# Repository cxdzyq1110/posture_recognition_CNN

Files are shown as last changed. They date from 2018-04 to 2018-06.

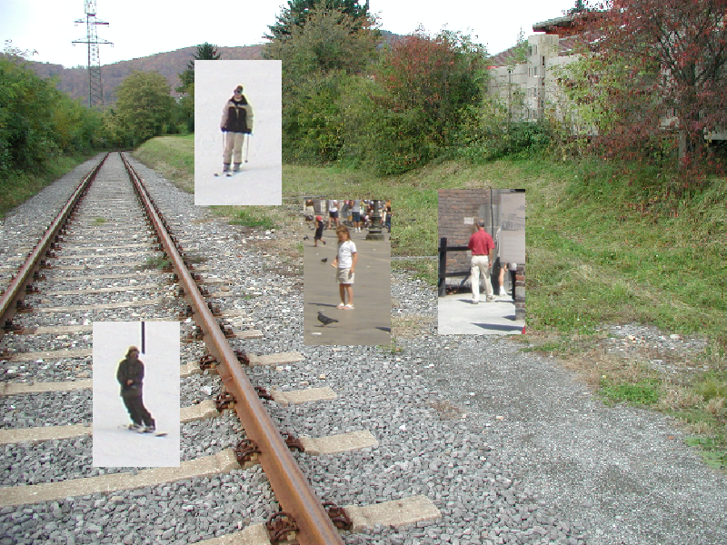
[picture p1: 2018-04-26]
projects/matlab/picture/test_hog_svm/no_person__no_bike_218.png

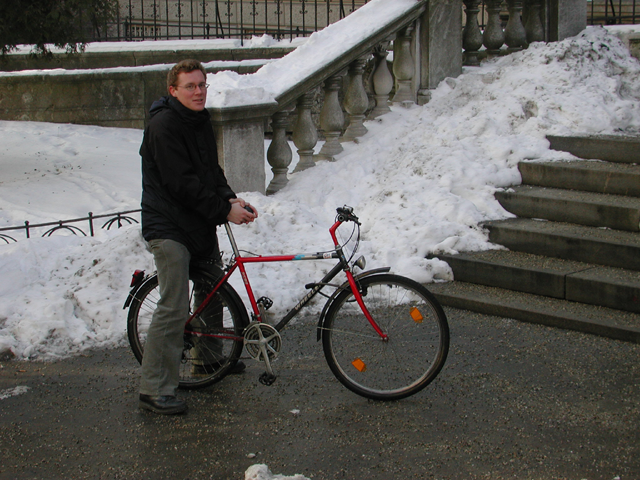
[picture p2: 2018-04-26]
projects/matlab/hog_svm/test.png

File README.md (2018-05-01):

# posture recognition based on CNN
To help machines learn what we human beings are doing via a camera is important. Once it comes true, machines can make different responses to all kinds of human's postures. But the process is very difficult as well, because usually it is very slow and power-consuming, and requires a very large memory space. Here we focus on real-time posture recognition, and try to make the machine "know" what posture we make. The posture recognition system is consisted of DE10-Nano SoC FPGA Kit, a camera, and an HDMI monitor. SoC FPGA captures video streams from the camera, recognizes human postures with a CNN model, and finally shows the original video and classification result (standing, walking, waving, etc.) via HDMI interface.

## documents
We upload our thesis here. And the details of the project is demonstrated.

## projects
We upload our projects, including Matlab, Python, and Quartus.  
And the software version is:  
> Matlab r2017b  
> Python 3.6.3  
> Anaconda 5.1.0  
> TensorFlow-gpu 1.3.0  
> Quartus 14.0

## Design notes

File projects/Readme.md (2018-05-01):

# ad9pcb					
> in the directory, there are files for PCB design of our pin-board between camera and DE10-Nano  
and We use Altium Design 9
				
# python					
> python codes using TensorFlow framework, train CNN and generate NPU instructions, and CNN parameters  
Anaconda 5.1.0  
Python 3.6  
Tensorflow r1.3  
							
# matlab					
> Matlab codes for LK optical flow, HOG+SVM simulation and ISA-NPU testing  
Matlab 2017b
				
# zFPGA\_lk\_optical\_flow		
> LK optical flow design for FPGA

# zFPGA\_cnn\_inst\_set\_arch	
> ISA-NPU design for FPGA

# zFPGA\_hog\_svm\_fpga		
> HOG+SVM static pedestrian detection for FPGA

# zFPGA\_DE10\_NANO\_SoC		
> total posture recognition system  
Quartus 14.0

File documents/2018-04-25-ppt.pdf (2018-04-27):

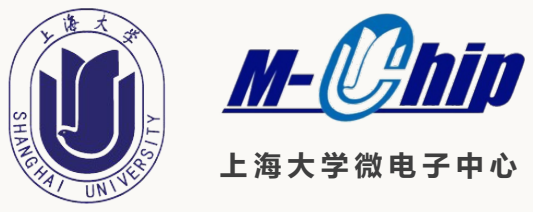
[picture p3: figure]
上海大学微电子中心

# Posture Recognition Based on Deep Learning

### Team: PR023

### Member: Xudong Chen, Yuqi Zhou, Mengjie Li Adviser: Prof. Zhangjin Chen

Microelectronics R & D Center, Shanghai University

## 1 Posture Recognition Based on Vision

Pedestrian Detection: find where the person is
Posture Recognition: recognize what posture it is Applications: somatic games, abnormal behavior detection, …

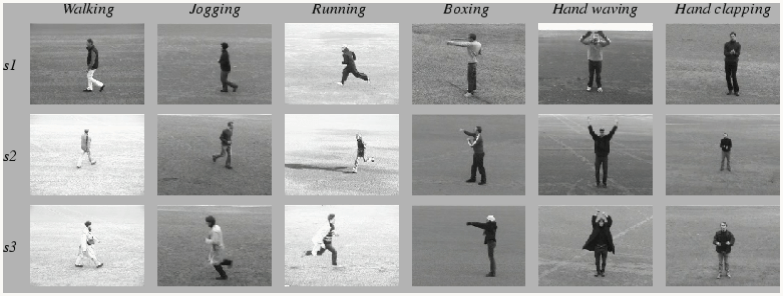
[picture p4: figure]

## 2 Posture Recognition Scheme

Two-Stream Convolution：compute optical flow in the video stream, and use video and optical flow as the input channels of CNN to recognize the posture
ISA-NPU: ADD / MULT / CONV / POOL / SIGM / TANH / …

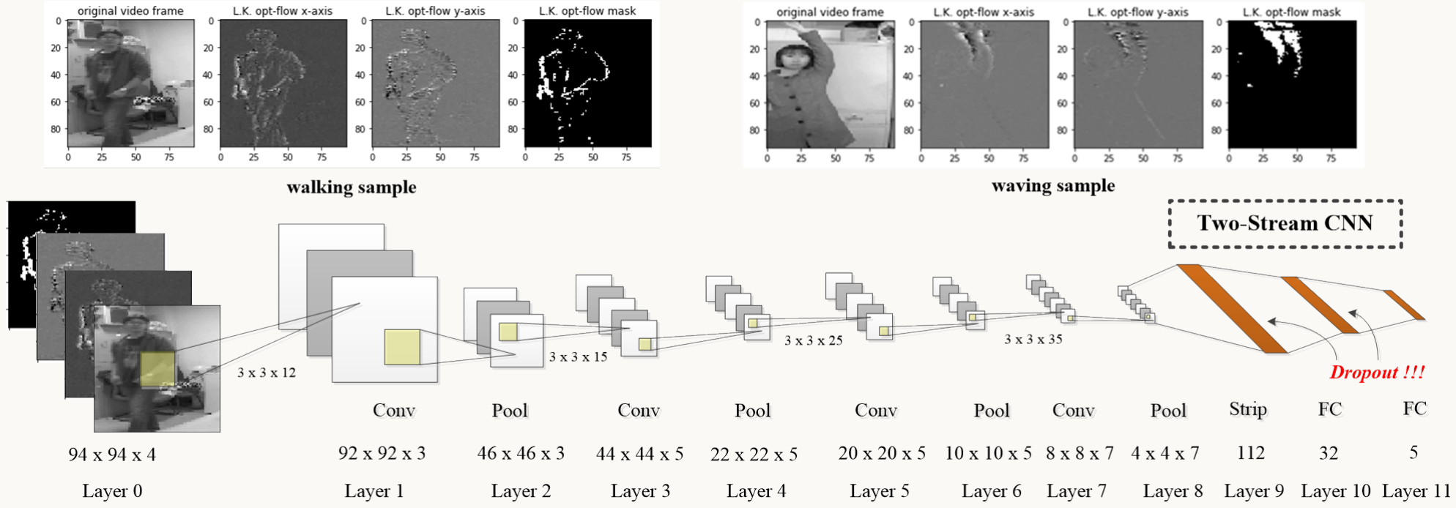
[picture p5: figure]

## 4 The Flow of Posture Recognition

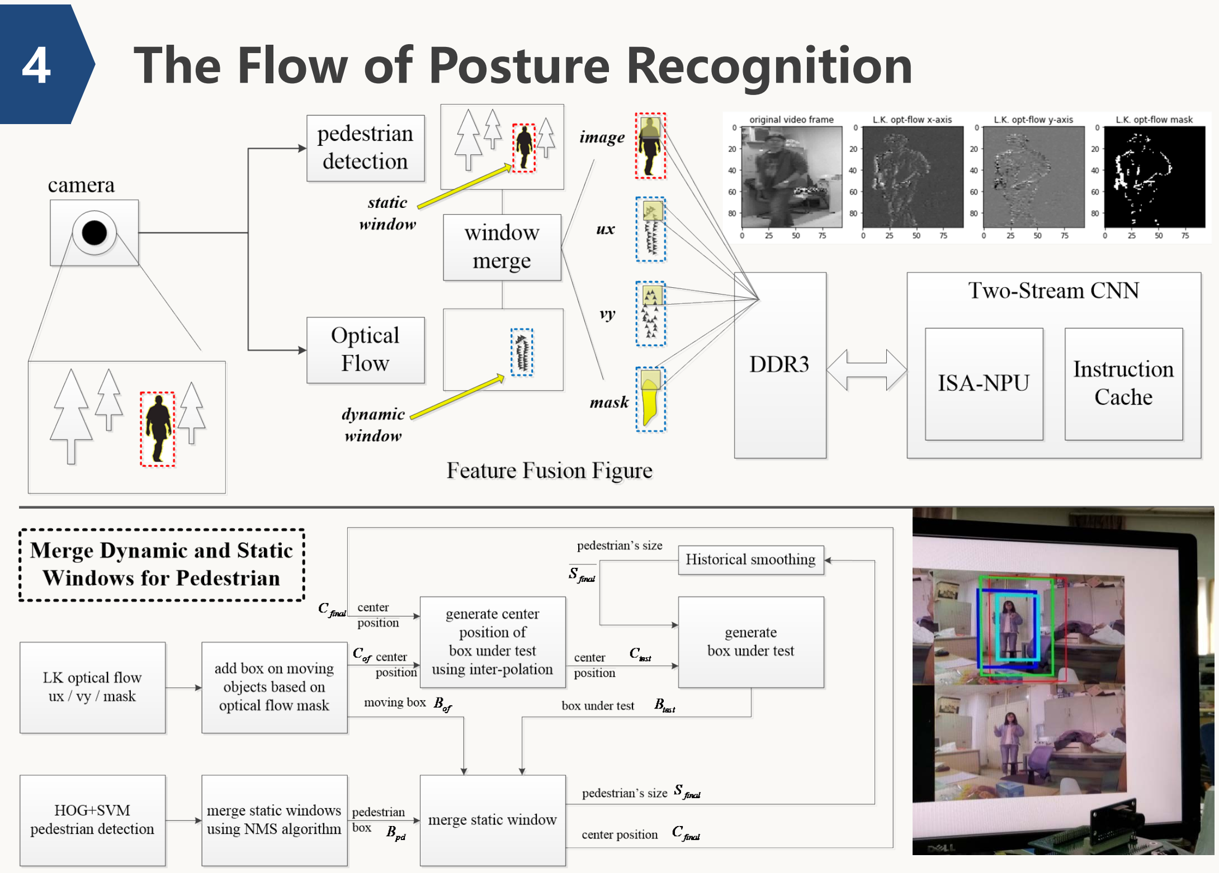
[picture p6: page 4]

## 5 Framework of the System

Co-process of software and hardware on DE10-Nano FPGA：optical flow, static detection, ISA-NPU, memory scheduler, video output; HPS：add box, NPU command；
Matlab：filter samples; Python：train the CNN model

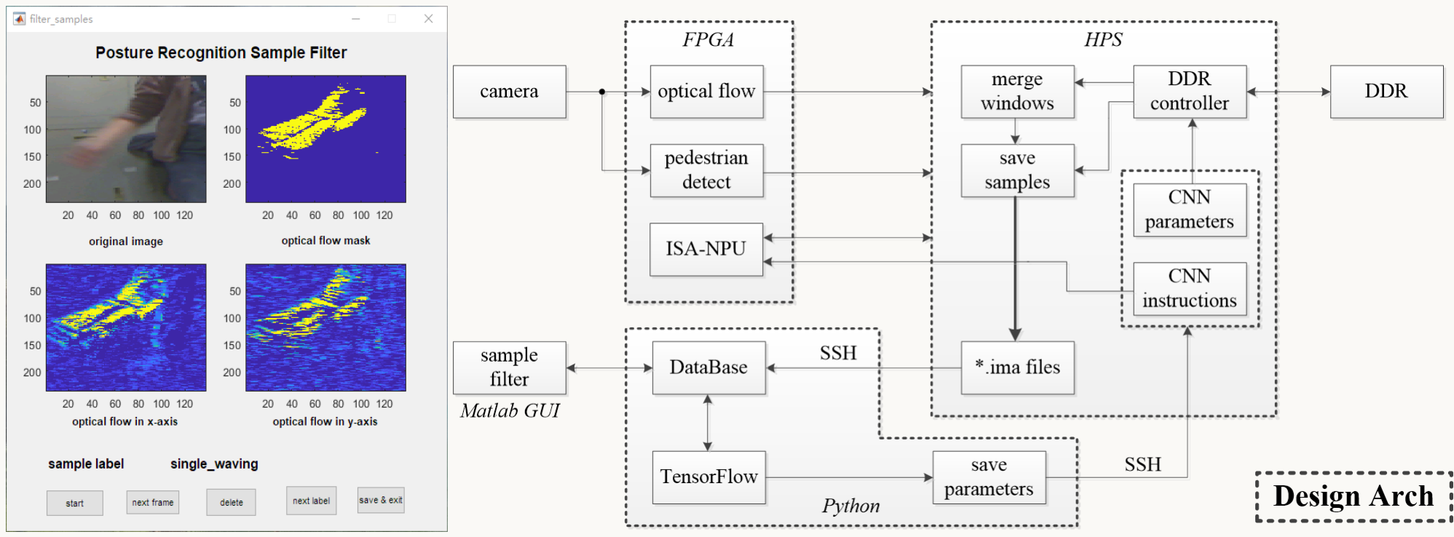
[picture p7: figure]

## 6 Performance of the System

Performance | LK Optical Flow | HOG + SVM | ISA-NPU
Speed | Fmax | 118.68 MHz | 76.8 MHz | 79.6 MHz
| Period | 800 x 600 | 800 x 600 | 814,177
| FPS | 247 | 160 | 97.7
Area | ALMs | 7,799 | 14,105 | 3,530
| Memory Bits | 188,202 | 1,167,512 | 73,984
| DSPs | 41 | 16 | 43
Performance | LK Optical Flow | HOG + SVM | ISA-NPU
Speed | Fmax | 35 MHz | 35 MHz | 66.67 MHz
| Period | 800 x 600 | 800 x 600 | 814,177
| FPS | 20 | 20 | 3.84
Performance | | Dynamic Window | Static Window | Merge Window
Time | | 70.2 ms | 11 us | 8 us

The theoretic limit of performance of modules

The experimental performance of hardware and software modules

Item | ALMs | Memory Bits | DSPs
Utility | 37,933 ( 91 % ) | 2,513,876 ( 44 % ) | 106 ( 95 % )

The resource usage of the total hardware system

## Conclusion and Outlook

We propose a posture recognition system that：
1. process optical flow, static pedestrian detection very fast, actually it is pipeline processing;
2. flexible for different CNN models, if the model changes, only parameters and NPU instructions should be re-generated;
3. recognize four postures with high precision: standing, squatting, waving and walking;
We can improve the system later in these aspects:

### 1. more postures can be recognized once the CNN model

grows；

### 2. high performance can be achieved if bandwidth of DDR

increases

7

# Thanks for Your Attention

GitHub https://github.com/cxdzyq1110/posture_recognition_CNN

Name Xudong Chen, Yuqi Zhou, Mengjie Li

Email chenxudong0318@gmail.com

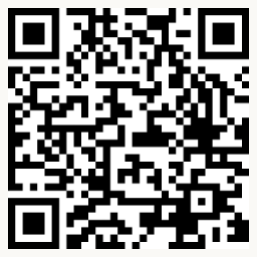
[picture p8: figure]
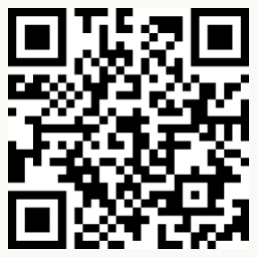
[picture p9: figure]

Team PR023 | innovatefpga | GitHub

## 6 Hardware Architecture

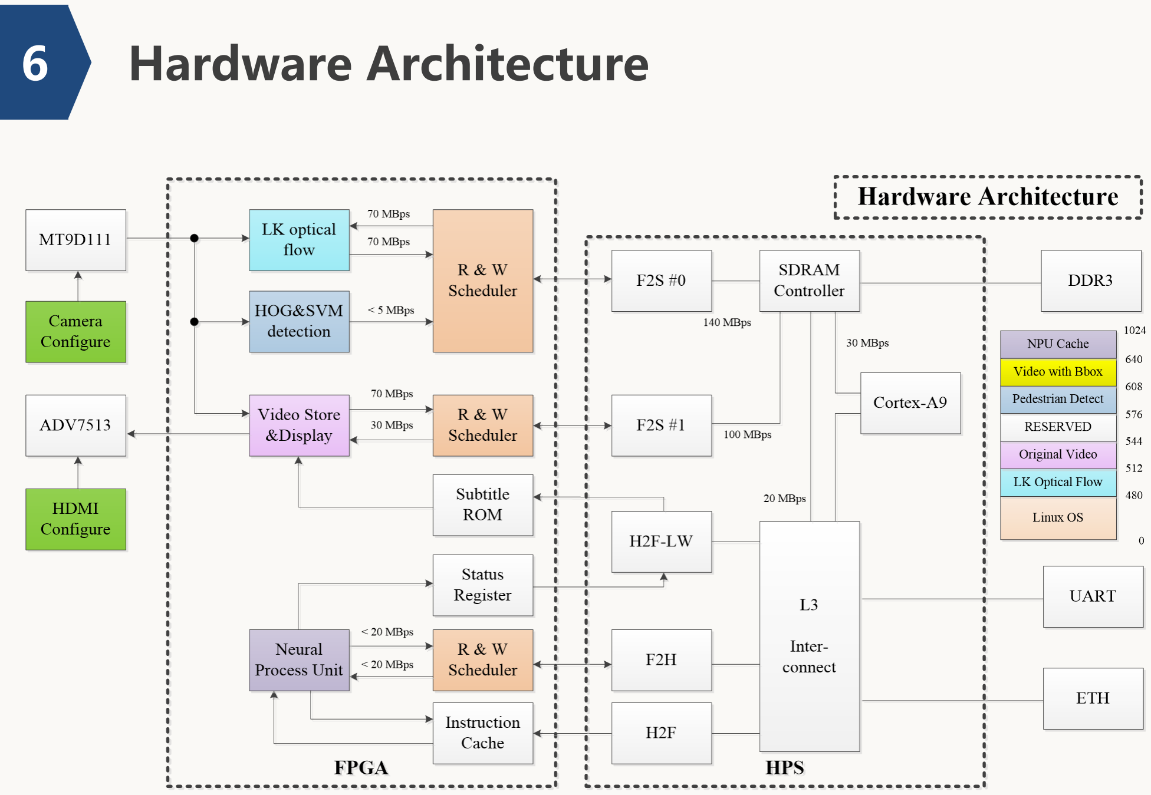
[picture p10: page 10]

## 7 Software Architecture

### Different Mode： 1. running mode：merge windows and recognize 2. sampling mode：merge windows and sample 3. testcnn mode：use training set to test CNN

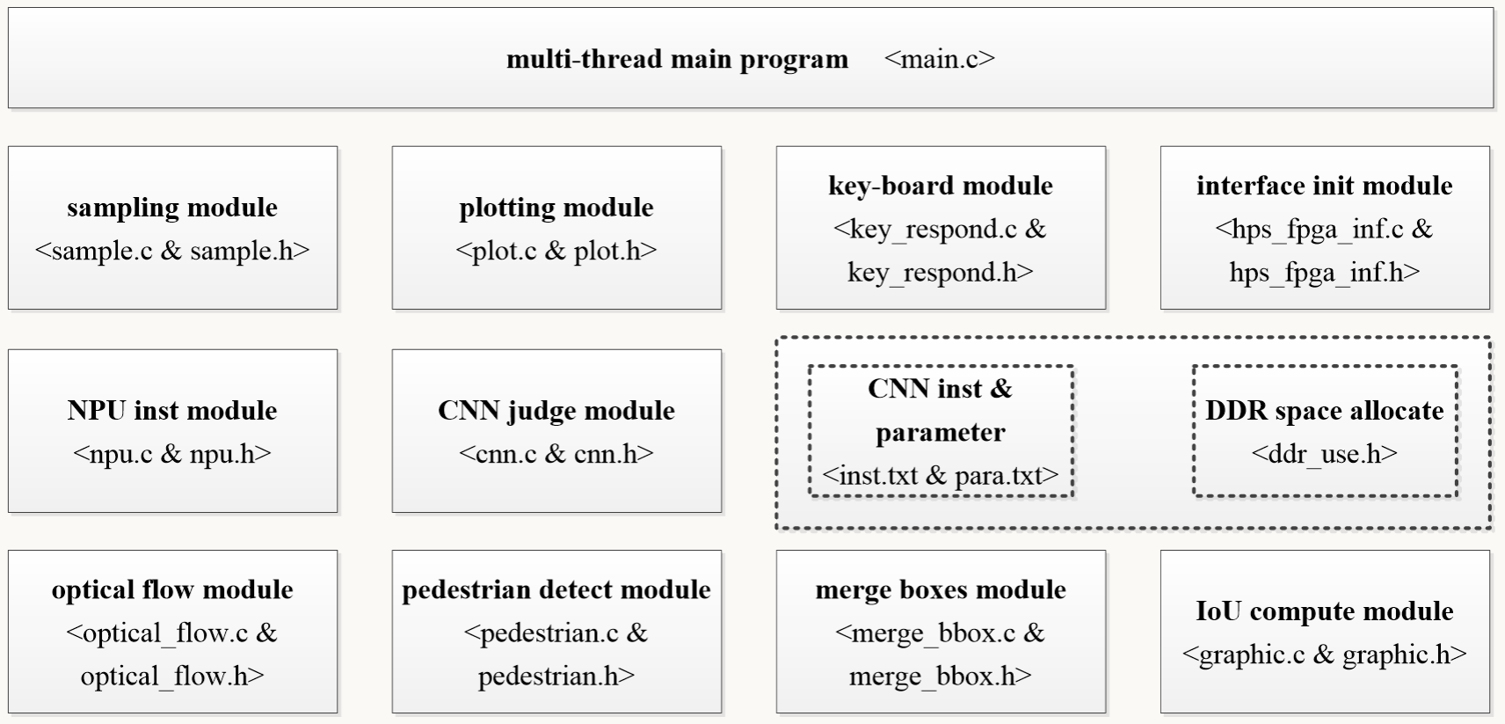
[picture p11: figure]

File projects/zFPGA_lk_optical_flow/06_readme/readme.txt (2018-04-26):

2018-02-06: 光流法的modelsim仿真+matlab绘图验证，另外，修正mux-port模块，提升DDR带宽利用率
			通过设置屏蔽字，巧妙地避开了DCFIFO的rdempty的1-clock延时，为光流法的运作提供了带宽支持
				单端口利用率：0-50%
				多端口利用率：0-100%
				
2018-02-21: 修改了光流法计算结果的存储格式
			|31|30|		29: 15		|		14:0		|
			|0 |M |     ux			|		vy			|
			其中，M表示Mask，即光流法计算结果，经过动态阈值比较后的判定结果
			ux/vy分别是计算的结果（光流速度），其运算结果缩小8倍得到的结果（即optical_u/optical_v[17:3]）

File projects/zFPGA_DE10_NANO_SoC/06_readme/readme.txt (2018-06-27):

// 基于深度学习的姿势识别项目
调试的记录
----------------------------
2018-01-25：
1. h2f/h2f_lw添加avalon_mm_pipeline是不行的，linux的内核boot不了
2. f2h/f2s都是可以增加avalon接口的
3. 在grhd工程的基础上进行修改，现在可以往DDR里面存放MT9D111数据（空间512~544MB）
4. 但是摄像头的配置还有问题（似乎RGB565数据流有问题）
5. 或者也有可能是DDR写入不正确

需要验证：
1. 是摄像头数据流问题？
2. 还是DDR写入的时候数据有丢失？
	（可以写一个调试的接口，按下按钮往DDR里面连续写入XX数据，然后读出，比较正确与否）
	
---------
2018-01-25:
1. 查明原因：是MT9D111的配置有问题，有几个地方是需要delay才行的！
	然后改好以后，在linux里面采集DDR数据，发送到PC显示，正确？
2. 关于ADV7513的配置还有问题！

---------
2018-01-27:
1. 发现DDR读取的时候，数量不对；
	a. 修改mux_port模块，改成了cam_rot_amp项目的即可
	b. 另外，解耦用的2-port的RAM也有时序问题？换成DCFIFO进行解耦（同时参考DCFIFO的q和rdempty）
	c. 再有就是MON_H_rd / MON_rd_req的生成也有问题（总之还是要用状态机控制才安全！）
2. 另外，DDR出来的数据会写入到FIFO里面，但是这个FIFO的VGA读取还有问题？
	应该是综合或者烧录的问题，多编译/烧录几次又可以了
3. 出现视频显示不稳定的情况（水平位移 & 上方噪声条）
	修改了HDMI的时序，又好了

2018-01-31：
1. 将HDMI改成是1024x768输出，65MHz像素时钟
2. ADV7513_DE的赋值需要修改成  ADV7513_DE <= (ADV7513_VCnt<VA && ADV7513_HCnt<HA);
3. 像素时钟的极性是不是也有影响？的确如此！看来走线延时挺大！

----------------------------------
2018-02-02:
1. 发现HPS正在preloader/u-boot的时候，FPGA不能去读写DDR，不然linux启动不了（或者说，u-boot会出错）
2. 发现FPGA把摄像头数据写入进去DDR没有问题（ima+matlab验证），但是ADV7513的HDMI输出数据源有问题
	查明原因：多读了很多的像素点数据！
	但是为什么会多读，似乎是cstate这个状态机的问题——被综合掉了？没有跳转逻辑，这就很奇怪！
	不对，在quartus里面，cstate会被综合成：cstate.0000 / cstate.0001 / cstate.0010 / cstate.0011 / ...
3. 另外，在modelsim仿真中发现，mux-port的port_num_fifo有溢出的可能，调整到4bx4096w大小
4. 还有，DDR中读取video视频数据，只是超前一行，不再超前两行
	读取的启动发生在：超前一行 & HDMI输出正好过了周围白色区域
	统计：DDR中读取出来的像素点数量 == 800
	统计：HDMI申请的像素点数量 == 800
	
-------------
2018-02-02:
1. 发现HDMI<--FIFO<--DDR读取的像素点数量不足够800点？超前2行进行读取？
2. 其实是因为DDR读取的时候太慢造成的，将HDMI输出降低到24fps的帧速，就没有问题了
3. 但是现在的问题在于：图像有水平（漂移造成？）的噪点，不确定是什么原因导致的
	如果只是输出彩条，那么图像很稳定，说明ADV7513 <-- FPGA这里没有问题
	猜测：	1. MT9D111的采集有偏差
			2. DDR读写有偏差
	
	测试：增加一个拨码开关，如果SW[0]==1，那么从DDR里读取出来的数据就是变成彩条，否则保持DDR理数据
			看看到底是DDR读取的问题，还是DDR写入/摄像头输出的问题？
			// 然后，可以根据SW拨码开关的状态，配置写入到line_buffer的数据是video数据/彩条测试图样
			发现：很稳定的彩色条纹！那么问题就出在DDR写入/读取/摄像头采集的问题！
	而通过HPS直接读取DDR中的图像，发现没有所谓的条纹问题，说明问题就出在DDR读取的数据不对！
	
	// 试图将MT9D111的MCLK加到65MHz，能不能提到系统的工作频率？
	无奈之下，选择替换mux-port多端口读写模块，牺牲一半的带宽，总之就是这个模块的问题！
	
	另外，修正了DDR中，512MB~1024MB都是视频采集的缓冲区（8MB/frame x 64frames）
	验证的时候，分别在512MB和1016MB的地方，读取一下DDR里面的数据，做成ima文件，发送到PC，看看有没有视频
	发现linux死机！看来一定要有相应的防范措施，防止linux的OS访问物理内存的高512MB数据，但是可以通过mmap来进行APP访问
	
---------
2018-02-02: 预留出512~1024MB地址的DDR存放视频数据
	尝试解决修正了DDR中，512MB~1024MB都是视频采集的缓冲区（8MB/frame x 64frames），导致linux死机的问题
	在software\spl_bsp\uboot-socfpga\include\configs\socfpga_common.h文件中，修改PHYS_SDRAM_1_SIZE参数，使得preloader和uboot只允许512MB的SDRAM
	不正确！
	实际上，是要在uboot的时候，修改mmcboot这个变量，添加mem=512M就可以实现高512MB空间预留给摄像头数据了
	验证：测试了512 MB 和1016MB 地址的8MB图像数据，发现确实是采集到的图像

---------
2018-02-04：将HDMI输出切割成4块，分别是【原始图像】【骨架图】【光流图】【判别图】
	另外，准备一个礼拜完成【骨架】【光流】的计算

---------
2018-02-06: 光流法的modelsim仿真+matlab绘图验证，另外，修正mux-port模块，提升DDR带宽利用率
			通过设置屏蔽字，巧妙地避开了DCFIFO的rdempty的1-clock延时，为光流法的运作提供了带宽支持
				单端口利用率：0-50%
				多端口利用率：0-100%
				
---------
2018-02-08: 修正了LK光流法模型中的一些小bug
			1. 在ux/vy计算完成后，需要计算速度的大小，这里使用了int_cordic_core模块，但是这个模块是32/16的配置，所以需要作出相应的修正
			2. 不对！其实是cordic算法中，ROM的初始化没有做好！
			3. 应该是VSYNC上升（有效）超前HSYNC（上升/有效）  6个PCLK，但是VSYNC下降又滞后于HSYNC下降6个PCLK
				也就是说：LK光流法模块里面没有来得及读取出DDR里面的（上一帧视频图像）
			4. 调换LK光流法和ADV7513-HDMI输出（对DDR的）读取接口port，将LK光流法的优先级排在HDMI输出的前面，结果发现HDMI输出受阻，看来F2S读取的带宽确实是需要认真考虑的问题
			5. 尝试：将MT9D111的采集时钟降一半，变成36 MHz的，这样整个系统的帧频也下降
			6. 另外，LK光流法读取到的“上一帧”好像有些问题？也不对，应该是1. LK光流结果的存储->2. HDMI输出时候读取LK光流，这两步存在问题
			7. 原来是 video_process 模块没有将 正在写入的块 CURR_FRAME 和上一次写入的块 PREV_FRAME 传递到 OpticalFlowLK 模块中去！
-----------------			
2018-02-12: 在LK光流法模块中增加了动态阈值的功能
	1. 动态阈值 + 4阶均值滤波
	
-------------------------------
2018-02-13：将项目迁移到DE10-Nano开发板下
	集成了MT9D111摄像头采集+LK光流计算+HDMI输出
	480 MB --> Linux OS
	32 MB --> LK Optical Flow
	512 MB --> Video RAM

-------------------------------
2018-02-21: 修改了光流法计算结果的存储格式
			|31|30|		29: 15		|		14:0		|
			|1 |M |     ux			|		vy			|
			[31]的1用来告诉ADV7513的line-buffer，这个数据是光流法的阈值判断结果，只要用[30]扩充就可以了
			其中，M表示Mask，即光流法计算结果，经过动态阈值比较后的判定结果
			ux/vy分别是计算的结果（光流速度），其运算结果缩小8倍得到的结果（即optical_u/optical_v[17:3]）

-------------------------------			
2018-03-02: 增加了HOG+SVM的行人检测代码，能将检测的结果保存到DDR的448MB~480 MB区间内
			存储的格式为：   [aa][bbbbbbbb][hhhhhhhhhhh][vvvvvvvvvvv]
			其中，aa=00:无效数据/ aa=01:表示1/1比例尺 / aa=10：表示1/2比例尺  /  aa=11:表示1/4比例尺
			bbbbbbbb = score/4096，直接移位12bit，应该足够存下了
			最后，hhhhhhhhh/vvvvvvvv就是bbox左上角所处的坐标位置
			另外，发现两个大问题：
			1. 板子的资源可能不太够
			2. OpenCL和普通的rtl怎么一同进行编译
			3. 怎么在14.0下开发OpenCL程序
	
	448 MB --> Linux OS
	32 MB --> Pedestrian Detection Result
	32 MB --> LK Optical Flow
	512 MB --> Video RAM		
--------------------
2018-03-03: 发现SVM判决器中的数据有溢出的情况
	1. 8-bit有符号数保存SVM中的w/b参数，所有参数x64取整（floor）
	2. 调整hog_svm_pd_rtl模块中的输出移位
	3. 调整hog_svm_pd_800x600/400x300/200x150中的行人检测阈值
	
	另外，HSG-SVM的参数，一定要用round进行【四舍五入】取整
	如果简单的ceil/floor进行向上/向下取整，会存在累积误差
	
	此外，1：2和1：4两个缩放后的图像中，HSG特征和matlab的结果有很大的区别，将近±33%，几乎就是完全不对的
	1：1原始图像的HSG特征和matlab结果差不多是±8%的误差

---------------
2018-03-06：使用Avalon-MM master/slave translator，将HPS和FPGA之间的AXI接口转换成Avalon接口
	1. F2S直接Avalon-MM，外部MT9D111摄像头采集&LK光流计算&行人检测结果
	2. F2H通过Avalon-MM-Master-Translator，实现HDMI数据的读取
	3. H2F通过Avalon-MM-Slave-Translator，实现HPS向FPGA传输数据，但是速率很慢，应该是AXI/Avalon协议转换造成的
	PS！后续应该要有AXI接口数据的直接读取，测试一下传输速率
	
----------
2018-03-07: 查明h2f/h2f_lw速度较慢的原因：Linux的问题
	1. 另外，通过Avalon-MM-Slave-Translator转接出来的h2f.lw接口，不会产生avalon_write信号！
	2. 发现将h2f传输数据量减小，h2f_lw就可以了
	3. 实测下来，h2f/h2f_lw都是低速的，询问工程师，理由是——Linux调度的问题
	4. 建议：fpga作为Avalon的master，通过f2h_axi_slave读取显示的缓存

----------
2018-03-16：添加了一份整体模块间调用的图readme(module).txt

-----------
2018-03-19: NPU架构集成、指令完成信号的交互
	1. 集成NPU架构进入系统工程，
	2. 同时通过H2F接口传输指令&FPGA超时等待机制确认指令传输完成
	3. 通过PIO交换NPU指令完成与否，以及MT9D111摄像头正在写入的区间【当然，这两个PIO信号必须set_false_path，否则时序违例】
	4. 增加NPU执行时钟周期计数到HPS.PIO的连接，用于确定NPU执行时间
	
-----------------
2018-03-19:
	1. 在NPU单元内部加入指令执行时间计算单元
	2. 修正了video_process模块中，HDMI输出的时候选取的视频来源（主要是0x09800000的行人检测加框结果）
	3. 行人检测效果不是特别的好，考虑原因如下：
		a. SVM训练样本挑选问题（正样本数量不够/负样本数量太多），改成2000/6000
		b. SVM定点算法误差较大，精度不够，改成10-bit小数位
		c. HSG的特征不足以解决此问题？暂时先不考虑这个可能性，因为有论文支撑这个HSG的正确/可行性
		【另外，需要将PD结果汇总写入DDR的score打分压缩1/16才可以，否则会有溢出的可能】
	4. 在HPS上用C语言实现了NMS非极大值抑制算法
		将内存空间0x2600_0000~0x2800_0000这32MB空间用于行人检测结果显示，有几种方案：
		a. 先将内存空间清空，然后将框内的图像输出到内存空间==>HDMI
		b. 将最新的图像复制到内存空间，并将框框打上去==>HDMI
		两种方案各有利弊，a方案速度快，b方案观察起来稳定，暂时先选择b方案

----------------
2018-03-21: 遇到了DDR读写带宽不够的问题！开放更多的f2s端口！
	1. 将HPS的C程序写成了多线程操作，MakeFIle修正，添加-lpthread选项
	3. 增加SVM参数的定点精度，到16bit整形定点存储，其中14-bit小数位
	4. 调整SDC文件约束，将摄像头输入时钟的频率设定在40 MHz，方便后端PR处理
	5. 开放两个f2s端口如下：
		f2s0 <----> LK光流法的读写 & 行人检测结果写入
		f2s1 <----> 视频的缓存 & HDMI输出
		f2h  <----> NPU单元的数据读写
		h2f  -----> 发送NPU指令
		h2f.lw <--- 接收NPU状态
	
P.S. 	试图将调用DDR读写控制器IP核的mux-port模块改写成burst传输的模式（假设最大的burst长度为4）【未果】
		注意DCFIFO的rdusedw/rdempty/rdfull等信号相对于rdreq存在的延时！
		测试环境：只剩下MT9D111视频输入/ADV7513视频输出，看看整个系统的极限频率
					然后调整mux-port的burst模式，看看视频采集是否正确，再看看系统的极限频率能否提高
		但是还要考虑burst的时候，有没有可能触碰到存储的边界！（所以mux-port模块还要有输入边界参数！）
		正确的burst条件是：rdusedw>=4 && 没有到达边界，这样可以启动burst x2，可以提升DDR控制器的读写带宽
	
----------------
2018-03-22: 修正了系统的时序
	1. 将HDMI读取DDR的时钟降低到80MHz
	2. NPU执行时间到HPS的接口也要set_false_path才行，或者需要DCFIFO进行跨时钟域的同步处理
	
--------------
2018-03-23: 光流计算中，上一帧视频没有完全读取出来！
	1. 使用更加高频的时钟去读取上一帧视频，这样的话，LK光流模块中的跨时钟域数据的同步就要用DPRAM来做了
	
----------
2018-03-26: 
	1. 行人加框结果也要缓存到2个内存块中，HPS通过PIO将正在写入的内存块记号传递给FPGA逻辑
	
---------
2018-03-27: 
	1. 为了减少M10K的占用，在行人检测模块中，SVM的VUT（待检测向量）需要拆分成H/L两半部分
	
2018-03-27: 试图减少资源占用，未果！
	1. 添加了一条RGB565转成灰度图像的指令[NPU]
    
---------
2018-03-29: 试图只用一个框将图像中的行人检测出来，未果
    1. 添加了光流法加框的算法（多尺度扫描）
    2. 怎么将HOG+SVM的行人检测方案和LK光流法的检测结果融合起来？
        LK光流：动态，运动物体准确，但是行人减速、只挥动手臂就会导致框缩小
        行人检测：静态，加框不准确，但是不会受到行人运动速度的影响
        
------------
2018-03-30: 添加NPU的指令RAM
    HPS通过H2F接口传输NPU指令，包括：
    1. 128'D0   表示NOP指令
    2. 128'D1   表示清空RAM的head指示（初始化指令RAM之前一定要传递该指令）
    3. 128'D2   表示执行RAM里面的指令（逐条执行）
    
2018-03-30：更新了SDC时序约束文件

---------------
2018-03-30：增加了框中数据的采集代码。

-----------
2018-04-07: 
	1. 增加了ADDs/SUBs两条指令
	2. 验证了基于NPU指令的CNN实现
	3. 增加了NPU指令发送、CNN网络参数存储、CNN网络输入数据等C语言接口
	
---------------
2018-04-09: 
	1. 将HPS端的C程序项目分模块加以保存和编译
	2. 整个系统测试运行，考察一下内容：
		1. NPU指令发布是否正确（正确）
		2. CNN输入数据是否正确
		3. CNN参数配置是否正确
		4. CNN计算过程是否正确（消耗时间大约是0.14 s ~ 0.25 s）
	3. linux下面的换行符是\n，windows下面的是\r\n
	4. 在python生成的sim_source文件夹中，有相应的CNN参数 & 原始数据的list文件
		这些文件的命名依照[sp-xx-label-yy.list]的规则，能够很方便的进行CNN硬件化验证
		通过这种“输入训练集样本进行CNN运行检验”的方法，可以确定问题出在【2,3,4】中
		最后，偶然发现：存储CNN参数的空间在mmap的时候，SPAN不够！
		修改之后，训练集数据可以跑通了
		
	5. 最后不得不承认！CNN过拟合了！
	
----------------
2018-04-18:
	1. 将NPU模块的读写两路请求端口分配到f2s0/f2h两路中；不要影响光流计算/HDMI输出;
	2. 将HDMI输出调整，右下角输出action-word，之后留给判别结果；
	3. 显示的顶部留给[posture recognition system]作为标语title
	
-----------
2018-05-23
	测试github能不能上传
	
----------
2018/6/27
	0. HDMI输出改到640x480@63Hz，HDMI、以及HDMI/VGA，接上各类显示器测试通过
	1. HDMI输出，2x2窗格显示，中间分隔
	2. word显示缩小，适应640x480
	3. linux的C代码，参数化

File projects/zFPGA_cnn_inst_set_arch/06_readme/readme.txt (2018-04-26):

2018-03-09：验证了CONV指令的正确性，增加TRAN函数
	1. CONV指令，和double双精度浮点数的相对误差为1e-5数量级
	2. POOL指令，average的pooling误差为0%；max-pooling的误差为0%
	3. 还有MULT矩阵乘法指令的验证
	3. 增加了TRAN矩阵转置的函数，后续为了优化MULT的时序，
		可以考虑增加TRAN_MULT指令，先转置，然后矩阵乘法（连续地址读取DDR很快）
		
2018-03-09: 为了防止综合，看看整个系统的资源消耗，发现CNN模块的资源占用如下：
	1. ALM：3631.8
	2. M10K：19
	3. DSP：46
	4. Fmax：54.67 MHz
	
2018-03-10: 为了证明CNN指令集架构计算的正确性，写了相应的python/matlab代码
	建立了一套验证平台，由python产生测试向量（初始化SSRAM），
	经过Modelsim仿真后，产生的运算结果写入到txt文件中
	在matlab里面比对python给出的正确结果和verilog运算的结果
	
2018-03-13: 修正了CNN的指令集架构，使得运算结果回写DDR的时候速度提升100%
	1. 这样，算上DDR数据读取，整体的DDR读写带宽速度提升了50%
	2. CNN指令单步运算的$3回写都改成是按行【优先】存储
	3. 另外，综合下来，资源和时序都优化了不少
	ALM: 3487.9
	M10K: 25
	DSP: 42
	Fmax : 71.21 MHz

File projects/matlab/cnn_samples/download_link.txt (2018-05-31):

链接：https://pan.baidu.com/s/15axLz94StUMhqZBAPDVOQA 密码：i6ar

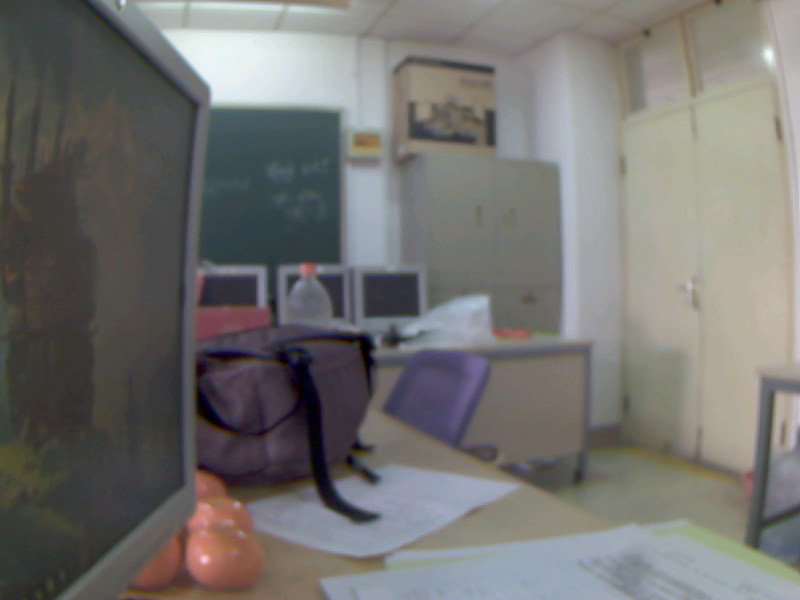
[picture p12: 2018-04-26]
projects/zFPGA_DE10_NANO_SoC/10_cpp_files/image/tt.png

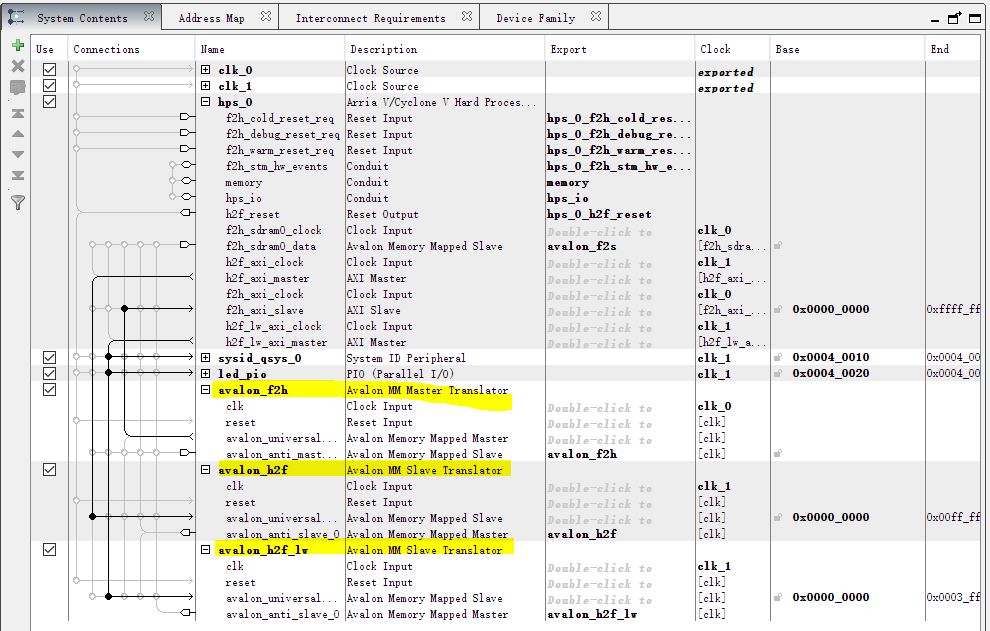
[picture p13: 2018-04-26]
projects/zFPGA_DE10_NANO_SoC/06_readme/h2f-f2h等接口的暴露.JPG

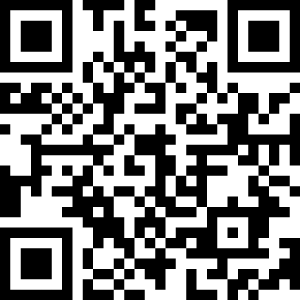
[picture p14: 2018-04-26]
documents/QR for our repo.png

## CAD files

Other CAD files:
projects/zFPGA_DE10_NANO_SoC/03_profiles/avalon_h2f_interafce.stp
projects/zFPGA_DE10_NANO_SoC/03_profiles/adv7513_i2c.stp
projects/zFPGA_DE10_NANO_SoC/03_profiles/mt9d111_i2c.stp
projects/zFPGA_DE10_NANO_SoC/03_profiles/cnn_inst.stp
projects/zFPGA_DE10_NANO_SoC/03_profiles/optical_flow.stp
projects/zFPGA_DE10_NANO_SoC/03_profiles/pd_bbox.stp
projects/zFPGA_DE10_NANO_SoC/03_profiles/multi_port_sdram_fifo.stp
projects/zFPGA_DE10_NANO_SoC/03_profiles/hog_svm.stp
projects/zFPGA_DE10_NANO_SoC/03_profiles/multi_port_sdram_fifo-f2h.stp

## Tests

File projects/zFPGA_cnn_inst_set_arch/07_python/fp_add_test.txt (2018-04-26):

-196608
-262144
-458752
393216
-524288
0
-393216
-65536
-393216
-196608
131072
196608
-196608
-327680
-196608
131072
-458752
65536
393216
0
-262144
-262144
196608
327680
-196608
-393216
262144
-524288
524288
-131072
262144
-65536
-65536
-131072
-589824
-131072
262144
-262144
-65536
262144
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

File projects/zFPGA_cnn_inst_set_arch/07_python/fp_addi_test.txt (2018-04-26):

525288
459752
394216
1180648
394216
918504
328680
721896
525288
787432
852968
1115112
721896
656360
656360
852968
328680
852968
1180648
984040
590824
656360
1115112
1180648
525288
328680
1049576
459752
1246184
590824
984040
787432
918504
590824
328680
721896
1049576
721896
656360
1246184
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

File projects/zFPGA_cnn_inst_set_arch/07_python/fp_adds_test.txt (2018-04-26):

393216
327680
262144
1048576
262144
786432
196608
589824
393216
655360
720896
983040
589824
524288
524288
720896
196608
720896
1048576
851968
458752
524288
983040
1048576
393216
196608
917504
327680
1114112
458752
851968
655360
786432
458752
196608
589824
917504
589824
524288
1114112
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

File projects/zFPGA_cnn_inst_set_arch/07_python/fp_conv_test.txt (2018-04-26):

-67764224
-73531392
-74907648
-81788928
-76152832
-72417280
-73990144
-83099648
-98304000
-94306304
-89391104
-84279296
-88145920
-86114304
-83886080
-80674816
-83361792
-84410368
-90308608
-77004800
-90701824
-99155968
-100139008
-80084992
-68222976
-69533696
-88604672
-94961664
-113639424
-97452032
-106233856
-102957056
-96993280
-82837504
-77725696
-97058816
-101384192
-106692608
-99155968
-106954752
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

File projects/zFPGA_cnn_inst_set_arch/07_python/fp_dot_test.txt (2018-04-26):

-5767168
-5046272
-5111808
-14155776
-5505024
-12845056
-3604480
-8650752
-7340032
-11796480
-9371648
-15597568
-10092544
-9830400
-8519680
-9371648
-3932160
-10223616
-14155776
-14745600
-7667712
-9175040
-15597568
-15335424
-5767168
-3604480
-12582912
-6881280
-13697024
-6488064
-10813440
-10223616
-13762560
-6488064
-4587520
-9371648
-12582912
-10813440
-7208960
-18677760
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

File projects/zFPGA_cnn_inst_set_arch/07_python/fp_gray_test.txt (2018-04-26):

194
130
55
120
94
177
132
73
64
132
160
181
161
139
155
149
174
161
170
48
165
89
58
94
123
114
113
122
100
69
71
61
100
123
122
142
94
168
174
121
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

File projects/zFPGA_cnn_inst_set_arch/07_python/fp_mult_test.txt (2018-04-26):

-44367872
-46202880
-51249152
-44826624
-37158912
-34144256
-40566784
-48889856
-52690944
-57671680
-51642368
-41418752
-39452672
-48758784
-40435712
-42860544
-47579136
-41943040
-34078720
-32178176
-39059456
-51707904
-54329344
-60489728
-53018624
-43450368
-40632320
-48824320
-44892160
-47382528
-53608448
-46661632
-37814272
-36241408
-43843584

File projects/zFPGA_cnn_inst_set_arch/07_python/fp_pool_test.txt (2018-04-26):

786432
1179648
917504
1048576
917504
1114112
1114112
1114112
1114112
1179648
786432
1245184
917504
1048576
1245184
1048576
1179648
720896
1179648
1245184
1179648
1179648
851968
1114112
1114112
1245184
917504
1245184
1179648
1179648
720896
589824
1179648
1114112
1245184
1048576
1245184
1245184
1048576
1048576
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

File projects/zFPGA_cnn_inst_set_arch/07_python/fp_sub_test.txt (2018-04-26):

1245184
1179648
1245184
1966080
1310720
1835008
1048576
1507328
1441792
1769472
1572864
2031616
1638400
1638400
1507328
1572864
1114112
1638400
1966080
1966080
1441792
1572864
2031616
2031616
1245184
1048576
1835008
1441792
1966080
1310720
1703936
1638400
1900544
1310720
1245184
1572864
1835008
1703936
1376256
2228224
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

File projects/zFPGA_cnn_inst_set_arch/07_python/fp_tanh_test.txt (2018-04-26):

-63176
-63173
-63171
-63169
-63167
-63164
-63162
-63160
-63158
-63155
-63153
-63151
-63148
-63146
-63144
-63142
-63139
-63137
-63135
-63132
-63130
-63128
-63125
-63123
-63121
-63119
-63116
-63114
-63112
-63109
-63107
-63105
-63102
-63100
-63098
-63095
-63093
-63091
-63088
-63086
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

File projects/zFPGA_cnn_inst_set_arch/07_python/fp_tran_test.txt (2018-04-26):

524288
786432
655360
327680
1245184
327680
327680
1114112
1114112
917504
458752
655360
458752
1179648
1245184
1048576
458752
851968
524288
327680
983040
589824
1048576
589824
524288
786432
1179648
524288
1245184
786432
786432
655360
458752
917504
393216
786432
786432
983040
1245184
327680
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

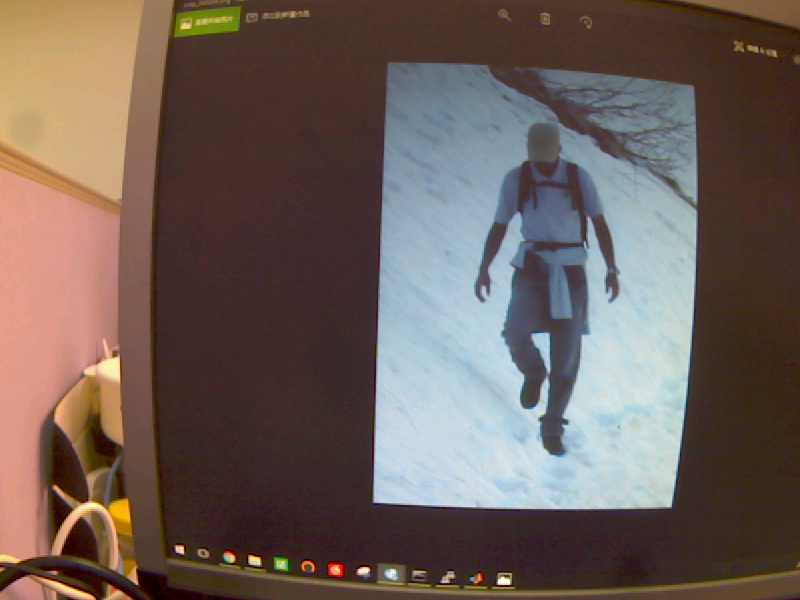
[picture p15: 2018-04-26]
projects/zFPGA_DE10_NANO_SoC/10_cpp_files/test.png

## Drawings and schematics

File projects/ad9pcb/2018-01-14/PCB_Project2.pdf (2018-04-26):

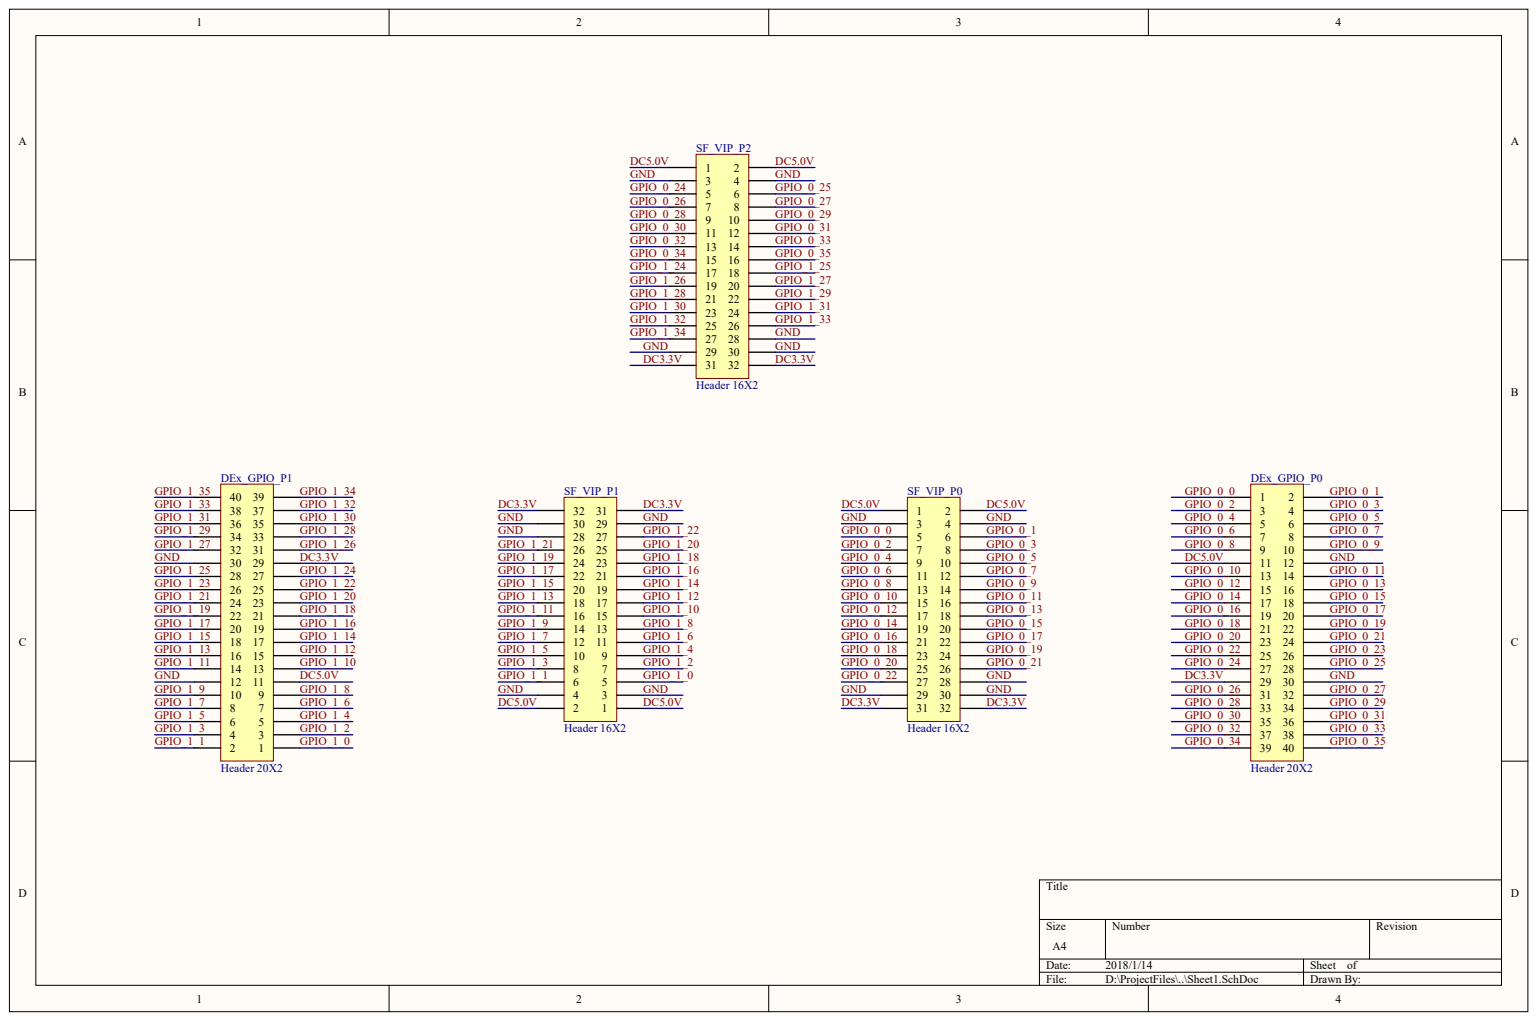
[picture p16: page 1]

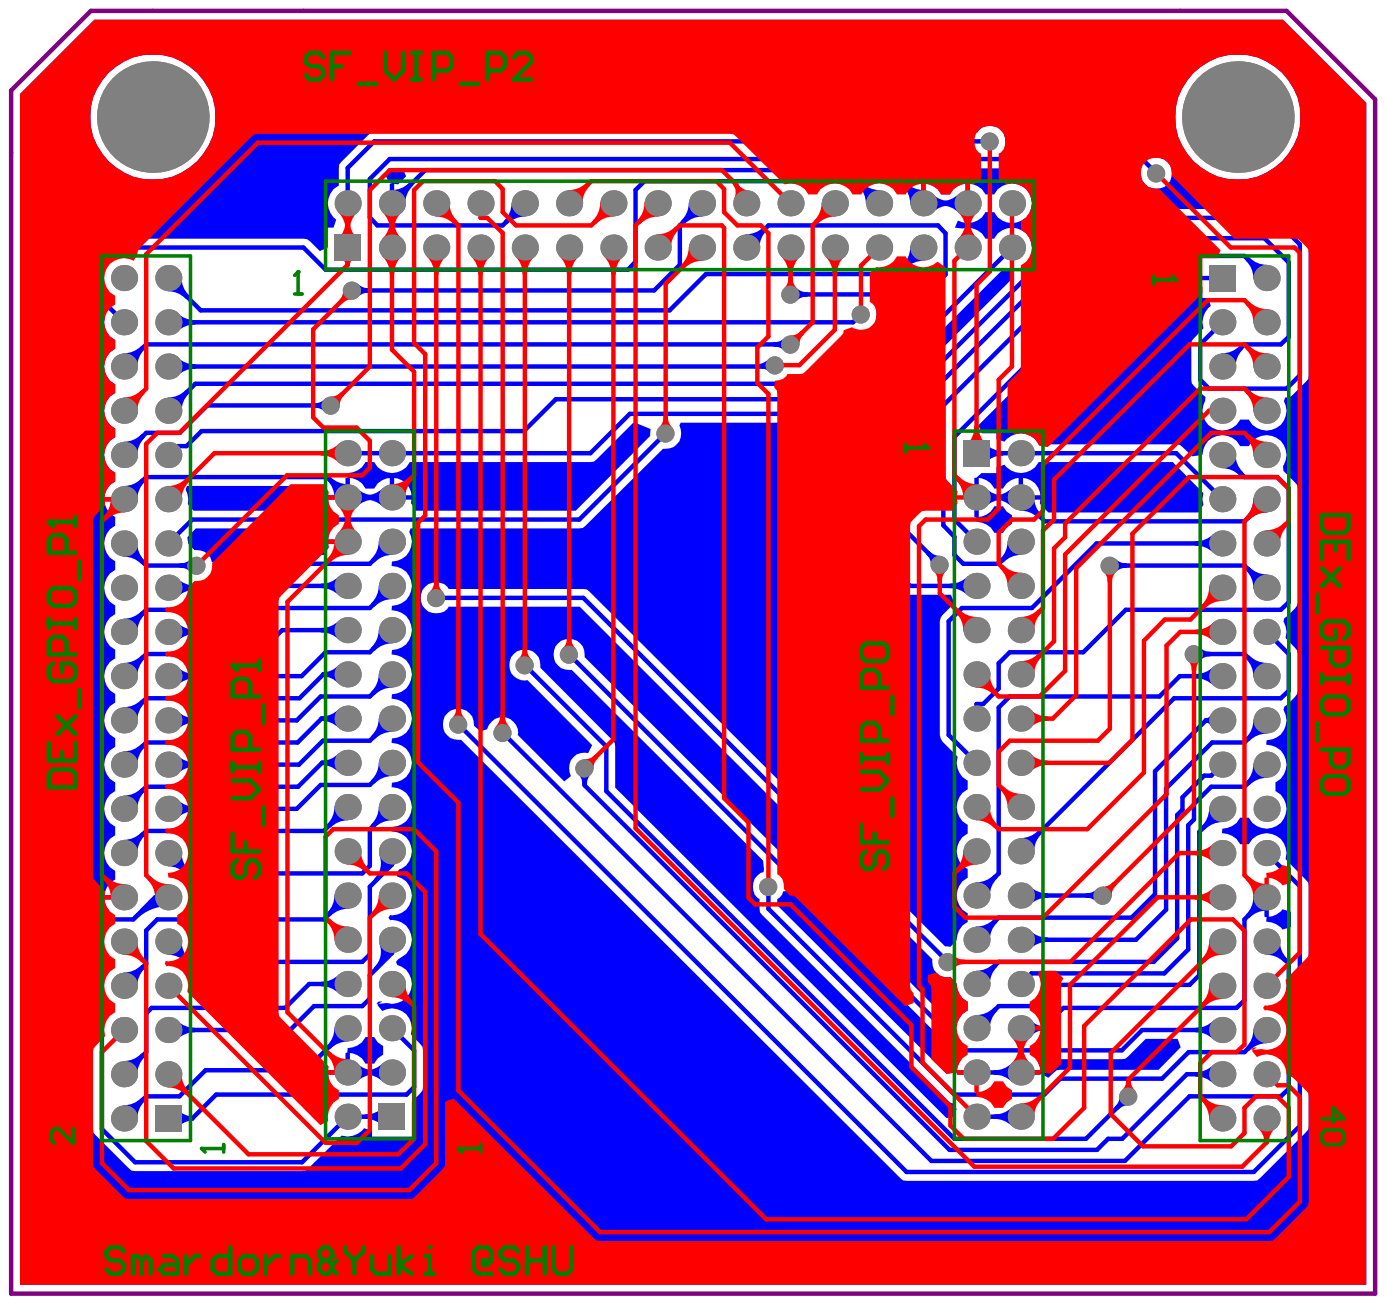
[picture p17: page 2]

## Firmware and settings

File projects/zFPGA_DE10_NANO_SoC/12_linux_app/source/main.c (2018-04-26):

#include <stdio.h>
#include <unistd.h>
#include <fcntl.h>
#include <stdlib.h>
#include <string.h>
#include <sys/mman.h>
#include <pthread.h>	// 多线程编程
#include <time.h>
#include "hwlib.h"
#include "socal/socal.h"
#include "socal/hps.h"
#include "socal/alt_gpio.h"
#include "../include/hps_0.h"

////
#include "../include/cnn.h"
#include "../include/ddr_use.h"
#include "../include/graphic.h"
#include "../include/hps_0.h"
#include "../include/hps_fpga_inf.h"
#include "../include/key_respond.h"
#include "../include/merge_bbox.h"
#include "../include/npu.h"
#include "../include/optical_flow.h"
#include "../include/pedestrian.h"
#include "../include/plot.h"
#include "../include/sample.h"

///////////////////////////////////////////////////////////////////////////////////
///////////////////////////////////////////////////////////////////////////////////
///////////////////////////////////////////////////////////////////////////////////
///////////////////////////////////////////////////////////////////////////////////
// NPU指令，128-bit
float npu_time ;	// npu指令执行时间
uint32_t	npu_inst_buffer[4];
// 一些全局变量
void *lw_h2f_virtual_base;	// lw.h2f接口的虚拟地址
void *h2f_virtual_base;		// h2f接口的虚拟地址
void *video_virtual_base;	// f2s接口（原始视频）映射的虚拟地址
void *pd_virtual_base;		// 行人检测空间映射后的虚拟地址
void *of_virtual_base;		// 光流计算结果存储空间映射后的虚拟地址
void *bbox_virtual_base;	// 加框以后的视频结果存储空间
void *bbox_memory_base;	// 加框以后的视频结果存储空间
void *cnn_para_virtual_base;	// CNN参数的存储空间
void *cnn_in_virtual_base;	// CNN输入的存储空间
void *cnn_out_virtual_base;	// CNN输出的存储空间
int fd;
//int loop_count;
int led_direction;
int led_mask;
void *h2f_lw_led_addr;		// led, ，通过h2f.lw接口写进去
void *h2f_lw_sysid_addr;	// system id，通过h2f.lw接口写进去
void *h2f_lw_ram_addr;		// ocram，通过h2f.lw接口写进去
void *h2f_lw_video_block_addr;		// mt9d111正在写入的区块，读取看看
void *h2f_lw_bbox_frame_addr;	// 加框以后的视频结果存储空间标记
void *h2f_lw_bbox_mask_addr;	// 用来存储加框的掩膜
void *h2f_lw_fpga_addr;		// fpga
void *h2f_lw_npu_addr;		// npu ready & time-count
void *h2f_ram_addr;
void *h2f_fpga_addr;

unsigned char mt9d111_block ;	// 查看现在摄像头的数据正在写入到DDR的哪一块内存区间 
unsigned char pd_bbox_frame;	// HPS正在写入的行人加框视频文件的内存块技术标记
	
void *pd_result_addr;
void *video_result_addr;
void *of_result_addr;	

// 行人检测的框
int pd_bbox[100][6];

// 合并PD & LK的加框结果
int final_bbox[1][6];
int of_bbox_shifter[of_bbox_shifter_len][6]; // 缓存过去检测到的光流法的框
int of_bbox_shifter_head;   // 指针头部
int of_bbox_shifter_sum[6];

int test_bbox[1][6];    // 待检测框

// 线程结束运行的标志
int thread_exit_falg;


// 光流法结果
unsigned char of_mask[300][400];
// 光流法的外部框
int of_bbox[1][6]; // [0]=hcnt, [1]=vcnt, [2]=width, [3]=height, [4]=enable, [5]=score

// 用于循环采样使用
int sample_time;    // 采样次数
// 记录采样的文件夹
char filedir[128];  //
int mode;   // 运行的模式，0-->正常模式 / 1-->采样模式 / 2-->没有CNN的运行模式
// 用来缓存数据
uint8_t 	test_f2s_read[1024];
// 时间戳
char time_stamp[128];

///////////////////////////////////////////////////////////////////////////////////
///////////////////////////////////////////////////////////////////////////////////
///////////////////////////////////////////////////////////////////////////////////
///////////////////////////////////////////////////////////////////////////////////
// 线程1，用来进行行人检测结果的NMS
void * thread_pd_bbox(void *);
// 线程2，用来检测按钮
void * check_keyboard(void *);
// 线程3，用来调度NPU
void * npu_inst_transfer(void *);
// 线程4，用来加载光流法
void * load_opt_flow_task_thread(void *);
// 线程5，用来绘图&加框处理
void * plot_thread(void *);
// 线程6，用来合并行人检测&光流加框的结果
void * merge_bbox_thread(void *);
// 线程7，采样
void * sample_bbox_thread(void *);
// 线程8，判别
void * cnn_judge_thread(void *);
// 线程8，判别一次
void * cnn_judge_once_thread(void *);

// 主函数
int main(int argc,char *argv[]) {
	//
    int i;
    system("clear");
    //
	if(init_all_interfaces())
		return 0;
	// 首先，让FPGA对DDR的访问启动
	*(uint32_t *)h2f_lw_led_addr = 0xFFFFFFFF;	// 全亮
	// 测试加上字幕
	add_word_display(1);
	// 初始化配置
	pd_bbox_frame = 0;	// 首先写入的是#0内存块
    sample_time = 0;
    for(i=0; i<6; i++){
        of_bbox_shifter_sum[i] = 0;
    }
    
    of_bbox_shifter_head = 0;   // 清除光流法的框的缓存空间
	// 延时一会儿
	usleep( 100*1000 );
	
	// 存储好NPU指令
	emit_all_npu_insts();	// 2018-04-09: 一旦运行这个函数，HPS就会奔溃？	
	// 存储好CNN的参数
	init_all_parameters();
	
	// 定义线程的 id 变量，多个变量使用数组
#define NUM_THREADS 10
    pthread_t tids[NUM_THREADS];
	
	// 首先测试一下最近一帧数据的读取结果
	read_last_frame();
    
    // 然后需要根据带入参数的值，确定需要调用的模式（running/sampling，即运行/采样）
    // 如果执行了 ./my_first_hps-fpga r  ，那么就是正常的运行模式
    if(argc==2 && !strcmp(argv[1], "r"))
    {
        printf("running mode...\n");
        mode = 0;   // 正常运行模式
        //return 1;
    }
	else if(argc==2 && !strcmp(argv[1], "tr"))
	{
		printf("running only once...\n");
		mode = 8;
	}
    // 如果执行了 ./my_first_hps-fpga rnc  ，那么就是没有CNN的运行模式（在CNN训练前，前期检查）
    else if(argc==2 && !strcmp(argv[1], "rnc"))
    {
        printf("running-without-CNN mode...\n");
        mode = 2;   // 没有CNN的运行模式
        //return 1;
    }
    // 如果执行了 ./my_first_hps-fpga rnc  ，那么就是没有CNN的运行模式（在CNN训练前，前期检查）
    else if(argc==2 && !strcmp(argv[1], "testcnn"))
    {
        printf("testing-CNN mode...\n");
        mode = 3;   // 测试CNN的模式
        //return 1;
    }
    // 如果执行了 ./my_first_hps-fpga s dir num  ，那么就是采样模式，会采集num次数，全部保存在dir文件夹中，加上时间戳标记
    else if(argc==4 && !strcmp(argv[1], "s"))
    {
        sample_time = atoi(argv[3]);
        strcpy(filedir, argv[2]);
        printf("sampling mode, dir = %s, times=%d...\n", filedir, sample_time);
        if(opendir(filedir)==NULL){
            printf("dir not exists, create one...\n");
            mkdir(filedir, S_IRWXU);
        }
        else{
            printf("dir already exists...\n");
        }
        mode = 1;   // 采样模式
        //return 1;        
    }
    // 否则就是无效指令，直接退出
    else{        
        printf("unvalid mode...\n");
        mode = 0;   // 正常运行模式
        return 0;
    }
	
    // 有CNN的运行模式
    if(mode==0)
    {
        // 首先清除线程结束的flag
        thread_exit_falg = 0;
        // 创建行人检测的线程
        pthread_create(&tids[0], NULL, thread_pd_bbox, NULL);
        // 创建按钮检测的线程
        pthread_create(&tids[1], NULL, check_keyboard, NULL);
        // 创建NPU调度的线程
        //pthread_create(&tids[2], NULL, npu_inst_transfer, NULL);
        // 创建加载光流法mask的线程
        pthread_create(&tids[3], NULL, load_opt_flow_task_thread, NULL);
        // 合并框线的线程
        pthread_create(&tids[4], NULL, merge_bbox_thread, NULL);
        // 创建绘图与显示的线程
        pthread_create(&tids[5], NULL, plot_thread, NULL);
        // 创建CNN判别的线程
        pthread_create(&tids[6], NULL, cnn_judge_thread, NULL);
        
        // 等待线程终止
        while(!thread_exit_falg)
            usleep(1000*1000);	// 
        
    }
    
    // 没有CNN的运行模式
    else if(mode==2)
    {
        // 首先清除线程结束的flag
        thread_exit_falg = 0;
        // 创建行人检测的线程
        pthread_create(&tids[0], NULL, thread_pd_bbox, NULL);
        // 创建按钮检测的线程
        pthread_create(&tids[1], NULL, check_keyboard, NULL);
        // 创建NPU调度的线程
        //pthread_create(&tids[2], NULL, npu_inst_transfer, NULL);
        // 创建加载光流法mask的线程
        pthread_create(&tids[3], NULL, load_opt_flow_task_thread, NULL);
        // 合并框线的线程
        pthread_create(&tids[4], NULL, merge_bbox_thread, NULL);
        // 创建绘图与显示的线程
        pthread_create(&tids[5], NULL, plot_thread, NULL);
        
        // 等待线程终止
        while(!thread_exit_falg)
            usleep(1000*1000);	// 
        
    }
    
    // 采样模式
	else if(mode==1){
        // 获取时间戳
        time_t tt; 
        time(&tt);  
        struct tm *t;  
        t = localtime(&tt); 
        ////printf("localtime %4d%02d%02d %02d:%02d:%02d\n", t->tm_year + 1900, t->tm_mon + 1, t->tm_mday, t->tm_hour, t->tm_min, t->tm_sec);
        sprintf(time_stamp, "%4d-%02d-%02d-%02d-%02d-%02d", t->tm_year + 1900, t->tm_mon + 1, t->tm_mday, t->tm_hour, t->tm_min, t->tm_sec);
        ////printf("%s\n", time_stamp);
        
        
        // 首先清除线程结束的flag
        thread_exit_falg = 0;
        // 创建行人检测的线程
        pthread_create(&tids[0], NULL, thread_pd_bbox, NULL);
        // 创建按钮检测的线程
        pthread_create(&tids[1], NULL, check_keyboard, NULL);
        // 创建NPU调度的线程
        //pthread_create(&tids[2], NULL, npu_inst_transfer, NULL);
        // 创建加载光流法mask的线程
        pthread_create(&tids[3], NULL, load_opt_flow_task_thread, NULL);
        // 合并框线的线程
        pthread_create(&tids[4], NULL, merge_bbox_thread, NULL);
        // 采样的线程
        pthread_create(&tids[5], NULL, sample_bbox_thread, NULL);
        // 创建绘图与显示的线程
        pthread_create(&tids[6], NULL, plot_thread, NULL);
        
        // 等待线程终止
        while(!thread_exit_falg)
            usleep(1000*1000);	// 
    }
	
	// 还要增加一个用来检测CNN运行正确与否的程序（在训练集中）
	// 在python生成的sim_source文件夹中，有相应的CNN参数 & 原始数据的list文件
	// 这些文件的命名依照[sp-xx-label-yy.list]的规则，能够很方便的进行CNN硬件化验证
	else if(mode==3){
		printf("testing our CNN module...\n");
		test_cnn_using_training();
	}
	
	// 测试是不是线程的问题？
	else if(mode==8){
		// 首先清除线程结束的flag
        thread_exit_falg = 0;
        // 创建行人检测的线程
        pthread_create(&tids[0], NULL, thread_pd_bbox, NULL);
        // 创建按钮检测的线程
        pthread_create(&tids[1], NULL, check_keyboard, NULL);
        // 创建NPU调度的线程
        //pthread_create(&tids[2], NULL, npu_inst_transfer, NULL);
        // 创建加载光流法mask的线程
        pthread_create(&tids[3], NULL, load_opt_flow_task_thread, NULL);
        // 合并框线的线程
        pthread_create(&tids[4], NULL, merge_bbox_thread, NULL);
        // 创建绘图与显示的线程
        pthread_create(&tids[5], NULL, plot_thread, NULL);
        // 创建CNN判别的线程
        pthread_create(&tids[6], NULL, cnn_judge_once_thread, NULL);
        
        // 等待线程终止
        while(!thread_exit_falg)
            usleep(1000*1000);	// 
	}
	
	//////////////////////
    // 关闭所有的接口
	if(close_all_interfaces())
		return 0;
	
	return( 0 );
}

//////////////////////////
///////////////
// 线程1，用来进行行人检测结果的NMS和加框处理
void * thread_pd_bbox(void * para)
{
	printf("thread_pd_bbox\n");
	while(!thread_exit_falg)
	{
		////printf("------ * * * --------\n");
		pd_windows_merge();
		//fake_pd_windows_merge();
		usleep(50000);	// 10ms延时
	}
}

// 线程2，用来检测按钮
void * check_keyboard(void * para)
{
	printf("check_keyboard\n");
	while(!thread_exit_falg)
	{
		if(mygetch() == 0x1B)
			thread_exit_falg = 1;
		usleep(200000);	// 100ms延时
	}
}

// 线程3，NPU指令控制
void * npu_inst_transfer(void * para)
{
	printf("npu_inst_transfer\n");
	while(!thread_exit_falg)
	{
		//printf("------ * * * --------\n");
		// 发射NPU指令
		send_npu_inst("ADDi", "0c000000,-189,0e000000,64,128");
		//test_npu_inst();
		usleep(10000);	// 10ms延时
	}
}

// 线程4， 加载光流法mask的函数
void * load_opt_flow_task_thread(void * para)
{
	printf("load_opt_flow_task_thread\n");
    while(!thread_exit_falg)
	{
		//printf("------ * * * --------\n");
        load_opt_flow_task();
		usleep(50000);	// 10ms延时
	}
}

// 线程5，用来绘图&加框处理
void * plot_thread(void * para)
{
	printf("plot_thread\n");
    while(!thread_exit_falg)
	{
		//printf("------ * * * --------\n");
        plot_picture_and_bbox();
		usleep(20000);	// 10ms延时
	}
}

// 线程6，合并
void * merge_bbox_thread(void * para)
{
	printf("merge_bbox_thread\n");
    while(!thread_exit_falg)
	{
		//printf("------ * * * --------\n");
        merge_bbox_task();
		usleep(10*1000);	// 10ms延时
	}
}

// 线程7，采样
void * sample_bbox_thread(void * para)
{
	printf("sample_bbox_thread\n");
    while(!thread_exit_falg && (sample_time--))
	{
		//printf("------ * * * --------\n");
        printf("sample %dth...\n", sample_time);
        sample_task(sample_time);
		usleep(50000);	// 10ms延时
	}
    thread_exit_falg = 1;
}

// 线程8，判别
void * cnn_judge_thread(void * para)
{
	printf("cnn_judge_thread\n");
	while(!thread_exit_falg)
	{
		//printf("------ * * * --------\n");
        cnn_run_judge();
		usleep(5000);	// 500ms延时
	}
}
// 线程8，判别一次
void * cnn_judge_once_thread(void * para)
{
	printf("cnn_judge_thread\n");
	usleep(5000*1000);	// 500ms延时
	//printf("------ * * * --------\n");
	cnn_run_judge();
	usleep(10000);	// 500ms延时
}
//////////////////////////////////////////////////////////////////////////////////

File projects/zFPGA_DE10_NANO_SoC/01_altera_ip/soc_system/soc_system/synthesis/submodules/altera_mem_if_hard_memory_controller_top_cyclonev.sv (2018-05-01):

// (C) 2001-2014 Altera Corporation. All rights reserved.
// Your use of Altera Corporation's design tools, logic functions and other 
// software and tools, and its AMPP partner logic functions, and any output 
// files any of the foregoing (including device programming or simulation 
// files), and any associated documentation or information are expressly subject 
// to the terms and conditions of the Altera Program License Subscription 
// Agreement, Altera MegaCore Function License Agreement, or other applicable 
// license agreement, including, without limitation, that your use is for the 
// sole purpose of programming logic devices manufactured by Altera and sold by 
// Altera or its authorized distributors.  Please refer to the applicable 
// agreement for further details.



`timescale 1 ps / 1 ps

(* altera_attribute = "-name FITTER_ADJUST_HC_SHORT_PATH_GUARDBAND 100" *)
module altera_mem_if_hard_memory_controller_top_cyclonev (
    afi_clk,
    afi_half_clk,
    ctl_clk,
    mp_cmd_clk_0,
    mp_cmd_clk_1,
    mp_cmd_clk_2,
    mp_cmd_clk_3,
    mp_cmd_clk_4,
    mp_cmd_clk_5,
    mp_cmd_reset_n_0,
    mp_cmd_reset_n_1,
    mp_cmd_reset_n_2,
    mp_cmd_reset_n_3,
    mp_cmd_reset_n_4,
    mp_cmd_reset_n_5,
    mp_rfifo_clk_0,
    mp_rfifo_clk_1,
    mp_rfifo_clk_2,
    mp_rfifo_clk_3,
    mp_rfifo_reset_n_0,
    mp_rfifo_reset_n_1,
    mp_rfifo_reset_n_2,
    mp_rfifo_reset_n_3,
    mp_wfifo_clk_0,
    mp_wfifo_clk_1,
    mp_wfifo_clk_2,
    mp_wfifo_clk_3,
    mp_wfifo_reset_n_0,
    mp_wfifo_reset_n_1,
    mp_wfifo_reset_n_2,
    mp_wfifo_reset_n_3,
    csr_clk,
    csr_reset_n,
    afi_reset_n,
    ctl_reset_n,
    avl_ready_0,
    avl_write_req_0,
    avl_read_req_0,
    avl_addr_0,
    avl_be_0,
    avl_wdata_0,
    avl_size_0,
    avl_burstbegin_0,
    avl_rdata_0,
    avl_rdata_valid_0,
    avl_ready_1,
    avl_write_req_1,
    avl_read_req_1,
    avl_addr_1,
    avl_be_1,
    avl_wdata_1,
    avl_size_1,
    avl_burstbegin_1,
    avl_rdata_1,
    avl_rdata_valid_1,
    avl_ready_2,
    avl_write_req_2,
    avl_read_req_2,
    avl_addr_2,
    avl_be_2,
    avl_wdata_2,
    avl_size_2,
    avl_burstbegin_2,
    avl_rdata_2,
    avl_rdata_valid_2,
    avl_ready_3,
    avl_write_req_3,
    avl_read_req_3,
    avl_addr_3,
    avl_be_3,
    avl_wdata_3,
    avl_size_3,
    avl_burstbegin_3,
    avl_rdata_3,
    avl_rdata_valid_3,
    avl_ready_4,
    avl_write_req_4,
    avl_read_req_4,
    avl_addr_4,
    avl_be_4,
    avl_wdata_4,
    avl_size_4,
    avl_burstbegin_4,
    avl_rdata_4,
    avl_rdata_valid_4,
    avl_ready_5,
    avl_write_req_5,
    avl_read_req_5,
    avl_addr_5,
    avl_be_5,
    avl_wdata_5,
    avl_size_5,
    avl_burstbegin_5,
    avl_rdata_5,
    avl_rdata_valid_5,
    afi_rst_n,
    afi_cs_n,
    afi_cke,
    afi_odt,
    afi_addr,
    afi_ba,
    afi_ras_n,
    afi_cas_n,
    afi_we_n,
    afi_dqs_burst,
    afi_wdata_valid,
    afi_wdata,
    afi_dm,
    afi_wlat,
    afi_rdata_en,
    afi_rdata_en_full,
    afi_rdata,
    afi_rdata_valid,
    afi_rlat,
    afi_cal_success,
    afi_mem_clk_disable,
    afi_ctl_refresh_done,
    afi_seq_busy,
    afi_ctl_long_idle,
    afi_cal_fail,
    afi_cal_req,
    afi_init_req,
    cfg_dramconfig,
    cfg_caswrlat,
    cfg_addlat,
    cfg_tcl,
    cfg_trfc,
    cfg_trefi,
    cfg_twr,
    cfg_tmrd,
    cfg_coladdrwidth,
    cfg_rowaddrwidth,
    cfg_bankaddrwidth,
    cfg_csaddrwidth,
    cfg_interfacewidth,
    cfg_devicewidth,
    local_refresh_ack,
    local_powerdn_ack,
    local_self_rfsh_ack,
    local_deep_powerdn_ack,
    local_refresh_req,
    local_refresh_chip,
    local_self_rfsh_req,
    local_self_rfsh_chip,
    local_deep_powerdn_req,
    local_deep_powerdn_chip,
    local_multicast,
    local_priority,
    local_init_done,
    local_cal_success,
    local_cal_fail,
    csr_read_req,
    csr_write_req,
    csr_addr,
    csr_wdata,
    csr_rdata,
    csr_be,
    csr_rdata_valid,
    csr_waitrequest,
    bonding_out_1,
    bonding_in_1,
    bonding_out_2,
    bonding_in_2,
    bonding_out_3,
    bonding_in_3,
    io_intaficalfail,
    ctl_init_req,
    local_sts_ctl_empty,
    io_intaficalsuccess
);

//////////////////////////////////////////////////////////////////////////////
// BEGIN PARAMETER SECTION

// Existing SIP parameters
parameter   AVL_SIZE_WIDTH                                                      = 0;
parameter   AVL_ADDR_WIDTH                                                      = 0;
parameter   AVL_DATA_WIDTH                                                      = 0;
parameter   MEM_IF_CLK_PAIR_COUNT                                               = 0;
parameter   MEM_IF_CS_WIDTH                                                     = 0;
parameter   MEM_IF_DQS_WIDTH                                                    = 0;
parameter   MEM_IF_CHIP_BITS                                                    = 0;
parameter   AFI_ADDR_WIDTH                                                      = 0;
parameter   AFI_BANKADDR_WIDTH                                                  = 0;
parameter   AFI_CONTROL_WIDTH                                                   = 0;
parameter   AFI_CS_WIDTH                                                        = 0;
parameter   AFI_ODT_WIDTH                                                       = 0;
parameter   AFI_DM_WIDTH                                                        = 0;
parameter   AFI_DQ_WIDTH                                                        = 0;
parameter   AFI_WRITE_DQS_WIDTH                                                 = 0;
parameter   AFI_RATE_RATIO                                                      = 0;
parameter   AFI_WLAT_WIDTH                                                      = 0;
parameter   AFI_RLAT_WIDTH                                                      = 0;
parameter   CSR_BE_WIDTH                                                        = 0;
parameter   CSR_ADDR_WIDTH                                                      = 0;
parameter   CSR_DATA_WIDTH                                                      = 0;
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

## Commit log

2018-04-26 2018-04-26: add documents(ppt&thesis), projects(FPGA,matlab,python)
    [PCB1.PcbDoc, PCB_Project2.PrjPCB, Sheet1.SchDoc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]
2018-05-01 2018-05-01: add IP core (in altera Quartus) into the repo
    [c5_pin_model_dump.txt]
2018-05-01 2018-05-01: add IP ocres in the total project
    [c5_pin_model_dump.txt, hps_sdram_p0_summary.csv]
2018-05-22 测试github能不能上传
2018-05-31 :memo: add samples for training cnn of posture recognition
2018-06-26 :sparkles: modify HDMI parameters, 640x480@63Hz
2018-06-27 0. HDMI输出改到640x480@63Hz，HDMI、以及HDMI/VGA，接上各类显示器测试通过 1. HDMI输出，2x2窗格显示，中间分隔 2. word显示缩小，适应640x480 3. linux的C代码，参数化
2018-06-28 :bug: 修正了pll参数
